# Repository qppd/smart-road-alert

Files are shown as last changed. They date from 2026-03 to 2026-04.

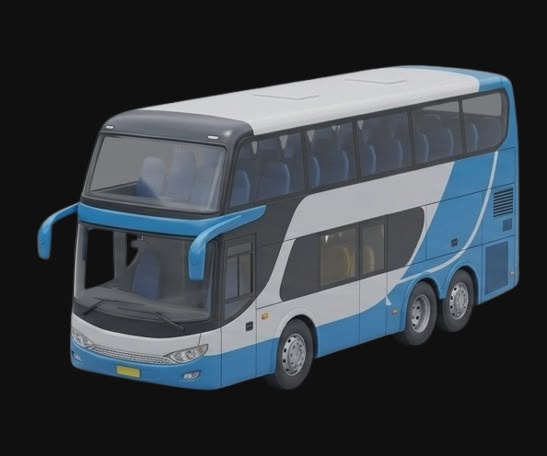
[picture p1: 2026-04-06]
src/rpi/SmartRoadAlertHost/images/bus.jpg

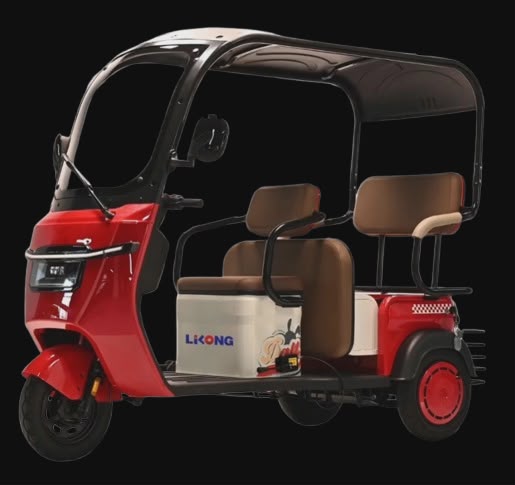
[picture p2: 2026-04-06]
src/rpi/SmartRoadAlertHost/images/ev_large.jpg

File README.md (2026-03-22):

# Smart Road Alert System

A real-time vehicle detection and alert system for improving driver safety on narrow, curved, and inclined roads through autonomous inter-post communication and intelligent traffic prioritization.

## Overview

Smart Road Alert is an intelligent roadside alert system designed for narrow, curved, and inclined road segments where restricted sightlines create blind spots and collision hazards. The system uses computer vision to detect approaching vehicles, estimate their speed and size, and communicate this information wirelessly between two roadside posts. Each post autonomously generates real-time driver alerts via LED displays and audio warnings.

This is a **two-node, symmetric, peer-to-peer architecture** where each post operates identically and bidirectionally, allowing drivers approaching from either direction to receive advance warning about oncoming traffic, enabling them to stop, slow down, or proceed safely.

## Key Features

- **Real-time Vehicle Detection**: YOLOv8-based object detection with multi-class classification (bike, car, truck, emergency vehicles, etc.)
- **Speed Estimation**: Continuous vehicle speed tracking from depth camera measurements
- **Wireless P2P Communication**: Bidirectional 433 MHz HC-12 radio links between roadside posts
- **Intelligent Prioritization**: Size-based vehicle classification with emergency vehicle fast-track handling
- **Kinematic-Based Emergency Detection**: Distinguishes active emergency responses from normal emergency vehicle traffic using speed, acceleration, and variance metrics
- **Multi-Modal Alerts**: Synchronized visual (LED display) and audio (voice/tone) warnings
- **Solar-Powered Deployment**: Off-grid capable with battery storage and MPPT charge management

## System Architecture

The system consists of two independent roadside posts (Post A and Post B) at opposite ends of a road segment. Each post operates identically with the same hardware and firmware.

```
Post A                          HC-12 433 MHz                     Post B
├─ OAK-D Lite Camera           ═════════════════────────────     ├─ OAK-D Lite Camera
├─ Raspberry Pi 5              (Bidirectional)                    ├─ Raspberry Pi 5
├─ ESP32 + HC-12 Radio                                            ├─ ESP32 + HC-12 Radio
├─ P10 LED Panel                                                  ├─ P10 LED Panel
└─ Audio Module                                                   └─ Audio Module
```

### Data Flow Pipeline

```
OAK-D Lite Camera
    ↓
Raspberry Pi 5 (Detection, Speed Estimation, Packaging)
    ↓
ESP32 (HC-12 Bridge)
    ↓
HC-12 Wireless Transmission (433 MHz)
    ↓ (over air)
    ↓
Remote ESP32 (HC-12 Reception)
    ↓
Remote Raspberry Pi 5 (Decision Logic & Prioritization)
    ├─→ ESP32 (Display Commands)
    │   └─→ P10 LED Panel
    └─→ Audio Module
```

This pipeline operates **bidirectionally and simultaneously**, with each post acting as both transmitter and receiver.

## Hardware Components

### Bill of Materials

| Component | Quantity | Purpose |
|---|---|---|
| Raspberry Pi 5 | 2 | Main processing (host controller) |
| ESP32 DevKitC | 2 | Display driver and HC-12 bridge |
| OAK-D Lite Camera | 2 | Vehicle detection and distance measurement |
| HC-12 Transceiver | 2 | 433 MHz wireless P2P communication |
| P10 LED Panel (32x16) | 6 (2 per post) | Visual driver alerts |
| DFPlayer Mini | 2 | Audio alert playback |
| Raspberry Pi SD Card | 2 | OS and application storage |
| Solar Panel | 2 | Energy Generation |
| LiFePO4 Battery (12V 50Ah) | 2 | Energy storage |
| SN74HC245N Octal Buffer | 5 | DC level shifting |

### Key Hardware Details

**Raspberry Pi 5**: Central processing unit for each post. Runs vehicle detection inference, speed estimation, wireless communication management, and decision logic.

**ESP32**: Dedicated microcontroller acting as a bridge between the Raspberry Pi (USB) and HC-12 radio. Also drives the P10 LED display independently to prevent display latency from blocking main processing.

**OAK-D Lite Camera**: Stereo depth camera with onboard Myriad X VPU. Provides high-resolution frames for detection and real-time depth (distance) measurements for speed calculation.

**HC-12 Transceiver**: Long-range, low-power 433 MHz serial radio module. Operates in transparent mode with 9600 baud UART connection to ESP32. Default channel: 433.4 MHz, Power: 20 dBm (100 mW maximum range).

**P10 LED Panel**: 32x16 high-brightness full-color LED matrix (HUB75 interface). Displays vehicle type, estimated speed, and action signal (GO, GO SLOW, STOP).

**DFPlayer Mini**: Compact MP3 player module. Plays pre-recorded voice alerts and tones from microSD card.

## Software Components

### Codebase Structure

```
src/
├── esp32/
│   └── SmartRoadAlertClient/
│       ├── SmartRoadAlertClient.ino      # Main firmware
│       ├── PINS_CONFIG.h                 # GPIO mappings
│       ├── SERIAL_CONFIG.h/cpp           # USB host communication
│       ├── HC12_CONFIG.h/cpp             # 433 MHz radio bridge
│       └── P10_LED_CONFIG.h/cpp          # Display control
│
└── rpi/
    ├── SmartRoadAlertHost/
    │   ├── main.py                       # Host controller entry point
    │   ├── serial_config.py              # ESP32 serial management
    │   └── requirements.txt              # Python dependencies
    │
    └── references/                       # Documentation and examples
```

### Raspberry Pi 5 Host (Python)

**main.py** - Entry point for the Smart Road Alert host application.

Responsibilities:
- Initialize and manage USB serial connection to ESP32 (SerialManager)
- Initialize and manage HC-12 wireless communication
- Run YOLOv8 camera inference in a background thread
- Process inbound messages from both ESP32 and remote post via HC-12
- Apply prioritization and decision logic
- Route display and audio commands
- Send periodic heartbeats and status requests

**Key Features**:
- Fully symmetric peer-to-peer architecture (both RPis run identical code)
- Thread-safe message queues for bidirectional communication
- Automatic ESP32 port discovery and reconnection
- Real-time camera inference (YOLOv8n at ~20 FPS)
- Graceful SIGINT/SIGTERM shutdown

**serial_config.py** - SerialManager module for USB communication with ESP32.

Handles:
- Automatic ESP32 device discovery (VID:PID matching)
- Handshake protocol (HELLO/ESP32_READY)
- Non-blocking line reader thread
- Connection monitoring and automatic reconnection
- Thread-safe message queue

### ESP32 Firmware (C++)

**SmartRoadAlertClient.ino** - Main firmware for ESP32.

Responsibilities:
1. Maintain USB-serial handshake link with host RPi (host heartbeat detection)
2. Drive the P10 HUB75 LED matrix display
3. Act as a transparent bridge for HC-12 radio traffic:
   - Receive `HC12_SEND` messages from RPi, transmit payload via HC-12
   - Receive HC-12 messages, wrap and forward to RPi as `HC12_RECV`
4. Forward vehicle telemetry data to RPi

**Communication Protocol**:
```
RPi → ESP32 (USB):
  {"type":"HC12_SEND","payload":"<escaped-json>"}

ESP32 → HC-12:
  <raw-json>

HC-12 → Remote ESP32 → Remote RPi (USB):
  {"type":"HC12_RECV","payload":"<escaped-json>"}
```

**Configuration Headers**:
- `PINS_CONFIG.h`: GPIO pin assignments for display, HC-12, serial
- `SERIAL_CONFIG.h`: USB communication parameters (baud, timeouts, handshake)
- `HC12_CONFIG.h`: HC-12 module settings (AT commands, baud, power)
- `P10_LED_CONFIG.h`: LED display refresh rates and rendering functions

## Communication Protocol

### HC-12 Wireless Link (433 MHz)

- **Frequency**: 433.4 MHz (default channel)
- **Baud Rate**: 9600 bps (factory default)
- **Power**: 20 dBm (100 mW, maximum range)
- **Range**: Up to 1 km in open field conditions
- **Message Format**: JSON over transparent UART

### Serial Communication Layers

```
Host RPi ←→ [USB Serial 115200 baud] ←→ ESP32 ←→ [UART 9600 baud] ←→ HC-12 Radio
```

The ESP32 acts as a bridge, transparently forwarding HC-12 messages while also managing P10 LED display updates independently.

### Message Types

**Vehicle Detection** (Local → Remote):
```json
{
  "type": "vehicle",
  "class": "truck",
  "speed": 25.5,
  "distance": 42.3,
  "timestamp": 1234567890.5
}
```

**RPI Heartbeat** (P2P):
```json
{
  "type": "RPI_PING",
  "node": "rpi-001"
}
```

**Display Command** (RPi → ESP32):
```json
{
  "cmd": "display",
  "state": "STOP",
  "vehicle": "truck",
  "speed": 25.5
}
```

## Vehicle Detection & Speed Estimation

### Detection Methods

The system supports two detection configurations:

**YOLOv8n (Recommended)**: YOLOv8 nano model running on Raspberry Pi 5 via ultralytics library. Achieves 20+ FPS on RPi 5 with headless deployment.

**DepthAI Pipeline** (Optional): YOLO inference running on OAK-D Lite's Myriad X VPU, enabling on-camera inference and spatial coordinate extraction. Reduces RPi CPU load at the cost of less flexible model updates.

### Supported Vehicle Classes

- **Small**: Bicycle, Motorcycle, EV Small
- **Medium**: Car, Tricycle, Tuktuk, Kariton, Police Car
- **Large**: Van, Jeepney, Bus, Truck, Ambulance, Fire Truck

### Speed Estimation Algorithm

Speed is estimated by tracking depth changes across consecutive frames:

```
speed (km/h) = (Δdistance / Δtime) × 3.6
```

Where:
- Δdistance = change in depth (meters) between consecutive frames
- Δtime = time elapsed between frames (seconds)
- 3.6 = conversion factor from m/s to km/h

Speed measurements are collected over a sliding observation window (0.5-1.0 second) to compute:
- **Mean Speed**: For direct alert decisions
- **Speed Variance** (std dev): For emergency vehicle kinematic detection
- **Acceleration**: For emergency response inference

## Decision Logic & Alert System

### Vehicle Prioritization (Normal Mode)

In normal (non-emergency) operation, the system prioritizes vehicles by size class:

```
Priority 1 (STOP) : Large Vehicles    (Van, Jeepney, Bus, Truck)
Priority 2 (WARN) : Medium Vehicles   (Car, Tricycle, Police Car)
Priority 3 (INFO) : Small Vehicles    (Motorcycle, Bicycle)
```

**Rationale**: Larger vehicles occupy more road width, require longer stopping distances on inclines, and create greater obstruction on curves. Therefore, larger vehicles receive right-of-way to minimize collision risk.

### Alert States

The P10 display shows one of three driver action signals:

- **GO**: Road is clear or low-obstruction vehicle detected. Drivers may proceed normally.
- **GO SLOW**: Medium-priority vehicle detected. Drivers should proceed with caution at reduced speed.
- **STOP**: Large vehicle detected or high-obstruction condition. Drivers must wait.

### Emergency Mode Detection

Emergency vehicles (ambulance, fire truck, police car) trigger **Emergency Mode** when detected with kinematic evidence of active emergency response. Three independent conditions can activate Emergency Mode:

**1. Speed Threshold**:
```
Detected Speed >= (Average Road Speed + Threshold)
```
Thresholds (road-type specific):
- Narrow or Curved: +10 km/h above average
- Inclined: +15 km/h above average
- Combined: +15 km/h above average

**2. Aggressive Acceleration**:
```
Longitudinal Acceleration >= 1.5 m/s² sustained for ≥ 2 seconds
```

**3. Speed Variance**:
```
Standard Deviation of Speed >= Variance Threshold (3-5 km/h default)
```

Emergency Mode requires **both emergency vehicle class AND at least one kinematic condition**. This dual-evidence requirement prevents false positives from static emergency vehicles or brief non-emergency speed bursts.

**Algorithm** (simplified):
```
Emergency Mode = (Emergency Vehicle Class Detected)
                 AND
                 [
                   (Speed >= Avg + Threshold)
                   OR (Acceleration >= 1.5 m/s²)
                   OR (Variance >= Threshold)
                 ]
```

### Emergency Mode Behavior

When Emergency Mode is activated:
- Emergency vehicle receives highest priority, overriding normal size-based prioritization
- Ambulances supersede all other vehicles including trucks
- Fire trucks prioritized based on speed/acceleration conditions (not variance alone)
- Police cars follow standard Emergency Mode logic
- Remote post immediately receives STOP signal
- LED display shows prominent emergency warning
- Audio module plays emergency alert tone

## Project Structure

```
smart-road-alert/
├── README.md                          # This file
├── LICENSE                            # MIT License
├── src/
│   ├── esp32/SmartRoadAlertClient/   # ESP32 firmware
│   │   ├── *.ino, *.h, *.cpp
│   │   └── PINS_CONFIG.h             # GPIO reference
│   │
│   ├── rpi/SmartRoadAlertHost/       # Raspberry Pi host application
│   │   ├── main.py                   # Entry point
│   │   ├── serial_config.py          # ESP32 manager
│   │   └── requirements.txt
│   │
│   └── sample/                        # Reference code & examples
│       ├── P10Led/                    # LED panel examples
│       └── yolo/                      # YOLO inference examples
│
└── wiring/
    └── SmartRoadAlertWiringDiagram.fzz  # Fritzing circuit diagram
```

## Dependencies

### Raspberry Pi 5 Host

**Python 3.8+** with the following packages:

```
pyserial>=3.5                          # USB serial communication
RPi.GPIO>=0.7.0                        # HC-12 SET pin control (GPIO17)
ultralytics>=8.0.0                     # YOLOv8n model and inference
opencv-python-headless>=4.8.0          # Camera capture (headless, no GUI)
```

Install via:
```bash
cd src/rpi/SmartRoadAlertHost
pip install -r requirements.txt
```

### ESP32 Firmware

Requires **Arduino IDE** or **PlatformIO** with:
- ESP32 board support package
- Arduino core for ESP32
- Standard libraries (Arduino.h, SoftwareSerial, etc.)

### Hardware Requirements

- Raspberry Pi 5 (2x for full system)
- ESP32 DevKitC (2x)
- OAK-D Lite camera (1x minimum, ideally 2x for testing)
- Linux OS (Raspberry Pi OS or similar)
- USB-A to Micro-B cable for ESP32 serial connection

## Configuration

### ESP32 Pin Configuration

Edit [src/esp32/SmartRoadAlertClient/PINS_CONFIG.h](src/esp32/SmartRoadAlertClient/PINS_CONFIG.h):

```cpp
#define PIN_HC12_RX   16   // HC-12 receives from this GPIO
#define PIN_HC12_TX   17   // HC-12 transmits to this GPIO
#define PIN_HC12_SET  22   // HC-12 mode select (LOW=AT, HIGH=transparent)
#define PIN_P10_A     12   // P10 address lines
#define PIN_P10_B     13
// ... (see full file for complete mapping)
```

### HC-12 Module Settings

Default configuration (factory settings):
- Mode: FU3 (transparent operation)
- Baud: 9600 bps
- Channel: CH001 (433.4 MHz)
- Power: Level 8 (20 dBm)

To configure via AT commands, set HC-12 SET pin LOW. [HC12_CONFIG.h](src/esp32/SmartRoadAlertClient/HC12_CONFIG.h) handles this automatically on startup.

### Raspberry Pi Host Configuration

Edit [src/rpi/SmartRoadAlertHost/main.py](src/rpi/SmartRoadAlertHost/main.py):

```python
ESP32_ENABLED: bool = True                    # Enable/disable ESP32
CAMERA_INFERENCE_ENABLED: bool = True         # Enable/disable camera
PING_INTERVAL_S: float = 5.0                  # Heartbeat interval
HC12_PING_INTERVAL_S: float = 5.0             # HC-12 heartbeat
NODE_ID: str = socket.gethostname()           # Node identifier
```

## Installation & Setup

### 1. Flash ESP32 Firmware

```bash
# Clone or download the repository
cd src/esp32/SmartRoadAlertClient

# Option A: Arduino IDE
# 1. Open SmartRoadAlertClient.ino
# 2. Select Board: ESP32 DevKitC
# 3. Select Port: /dev/ttyUSB0 or COM port
# 4. Click Upload

# Option B: PlatformIO (if using VSCode)
# 1. Install PlatformIO extension
# 2. Run: pio run -t upload
```

Verify upload in serial monitor (9600 baud):
```
[SmartRoadAlertClient] Ready
```

### 2. Install Raspberry Pi OS on RPi 5

- Download Raspberry Pi Imager
- Flash Raspberry Pi OS (64-bit) to SD card
- Enable SSH and I2C during imaging (optional but recommended)
- Boot and configure

### 3. Install Python Dependencies

```bash
cd src/rpi/SmartRoadAlertHost

# Create virtual environment (recommended)
python3 -m venv venv
source venv/bin/activate

# Install dependencies
pip install --upgrade pip
pip install -r requirements.txt

# Note: RPi.GPIO requires hardware GPIO access; test with:
python3 -c "import RPi.GPIO; print('GPIO OK')"
```

### 4. Test USB Connection to ESP32

```bash
cd src/rpi/SmartRoadAlertHost

# Quick connection test
python3 -c "from serial_config import SerialManager; m = SerialManager(); m.start(); print('Connected:', m.is_connected()); m.stop()"
```

Expected output:
```
15:32:01 [INFO] serial_config: Attempting to connect to ESP32...
15:32:02 [INFO] serial_config: Connection established; handshake successful.
Connected: True
```

### 5. Run Host Application

```bash
cd src/rpi/SmartRoadAlertHost
python3 main.py
```

Expected console output:
```
2026-03-22 15:32:15 [INFO] SmartRoadAlert: Smart Road Alert Host starting.
2026-03-22 15:32:16 [INFO] SmartRoadAlert: Camera inference thread started.
2026-03-22 15:32:16 [INFO] SmartRoadAlert: Main loop running. Press Ctrl+C to stop.
```

## Usage & Operation

### System Operation

Once both posts are running, they automatically:

1. **Detect Vehicles**: YOLOv8 runs at ~20 FPS, classifying all visible vehicles
2. **Estimate Speed**: Continuous depth tracking produces real-time speed estimates
3. **Exchange Data**: Each post wirelessly transmits its local detections to the remote post via HC-12
4. **Apply Logic**: Receive local and remote data, prioritize by size/emergency status
5. **Display Alerts**: Update LED panel and play audio warnings based on decision logic

### Example Scenario

**Scenario**: A motorcycle (low priority) approaches Post A from the left at 12 km/h; no vehicles at Post B.

**Post A Actions**:
1. Detects motorcycle via OAK-D Lite
2. Estimates speed: 12 km/h
3. Transmits via HC-12: `{"type":"vehicle","class":"motorcycle","speed":12,"distance":25}`
4. Applies logic: low-priority vehicle, safe passage
5. Sends to ESP32: `{"cmd":"display","state":"GO","vehicle":"motorcycle"}`
6. P10 LED shows: motorcycle icon, "12 km/h", "GO" signal
7. Audio module: silent (GO state)

**Post B Actions**:
1. Receives motorcycle data from remote Post A via HC-12
2. No local detections
3. Applies logic: single low-priority vehicle, safe for drivers on Post B side
4. Sends to ESP32: `{"cmd":"display","state":"GO SLOW"}`
5. P10 LED shows: motorcycle icon, "GO SLOW" signal
6. Audio module: "Vehicle approaching, proceed with caution"

### Emergency Vehicle Example

**Scenario**: An ambulance detected at Post A traveling at 40 km/h (average road speed: 20 km/h).

**Detection Phase**:
1. YOLOv8 detects class: "ambulance"
2. Speed estimate: 40 km/h
3. Acceleration: 1.8 m/s² (sustained)
4. Emergency Mode Trigger: YES (speed >= 20 + 15, acceleration >= 1.5 m/s²)

**Response**:
- Post A LED: Shows emergency warning + "STOP" signal
- Post A Audio: "EMERGENCY VEHICLE - PLEASE STOP"
- HC-12 transmits: `{"type":"vehicle","class":"ambulance","emergency":true,"speed":40}`
- Post B LED: Shows emergency warning + "STOP" signal (highest priority override)
- Post B Audio: "Emergency vehicle approaching - stop immediately"

### Monitoring & Debugging

Check system status in real-time:

```bash
# Monitor console output (already visible during main.py execution)
# Press Ctrl+C to gracefully stop

# Check HC-12 communication:
# Monitor serial output on both RPis to verify wireless packet exchange

# Test camera:
python3 -c "import cv2; cap = cv2.VideoCapture(0); print('Camera:', cap.isOpened())"

# Check system logs:
journalctl -u smartroadaler -f  # If installed as systemd service
```

## Troubleshooting

| Issue | Cause | Solution |
|---|---|---|
| ESP32 not detected | USB not connected or wrong SO baud rate | Check /dev/ttyUSB* ports, reinstall drivers |
| Handshake timeout | Serial connection unstable | Try higher baud rate, shorter USB cable |
| No HC-12 communication | Radio not powered or wrong channel | Verify power supply, check AT command config |
| YOLOv8 not starting | ultralytics package missing | `pip install ultralytics` |
| Camera not found | /dev/video0 unavailable | Check USB camera connection, list with `ls /dev/video*` |
| P10 display blank | GPIO pin mismatch or power issue | Verify PINS_CONFIG.h, check 5V supply to LED panel |

## Performance Metrics (Reference)

- **Detection FPS**: 20+ FPS (YOLOv8n on RPi 5)
- **Speed Estimation Latency**: <100 ms per frame
- **HC-12 Wireless Range**: Up to 1 km (open field)
- **HC-12 Message Latency**: 10-50 ms per message
- **LED Display Refresh**: 60 Hz (16.7 ms per frame)
- **Decision Logic Latency**: <50 ms (prioritization + routing)

**Total System Latency**: ~200-300 ms from detection at Post A to alert display at Post B (under ideal conditions).

## Future Improvements

- **DepthAI Pipeline**: Offload detection to OAK-D Lite VPU for lower RPi CPU load
- **Machine Learning**: Train custom YOLO model on local road vehicle dataset for improved accuracy
- **Sensor Fusion**: Combine camera with radar or LiDAR for robust detection in adverse weather
- **Advanced Analytics**: Track vehicle history, detect unusual patterns, generate statistical reports
- **Web Dashboard**: Remote monitoring of both posts via HTTP/MQTT
- **Mobile App**: Driver notifications via Bluetooth or cellular link
- **Enhanced Audio**: Context-aware alerts ("Truck from left approaching, slow down")

## License

This project is licensed under the MIT License. See [LICENSE](LICENSE) file for details.

## Authors

Developed by Sajed Lopez Mendoza (2026)

---

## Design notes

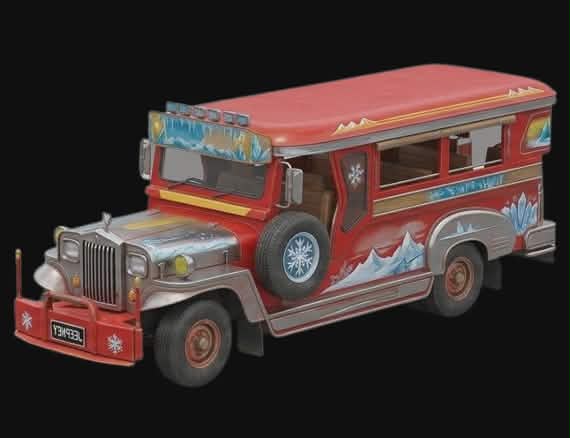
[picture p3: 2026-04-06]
src/rpi/SmartRoadAlertHost/images/jeepney.jpg

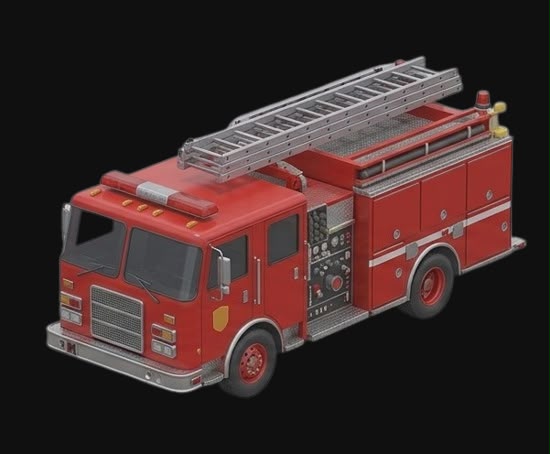
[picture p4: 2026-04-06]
src/rpi/SmartRoadAlertHost/images/fire_truck.jpg

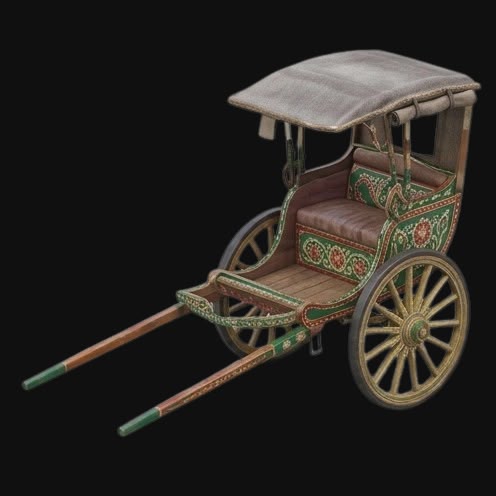
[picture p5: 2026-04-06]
src/rpi/SmartRoadAlertHost/images/kalesa.jpg

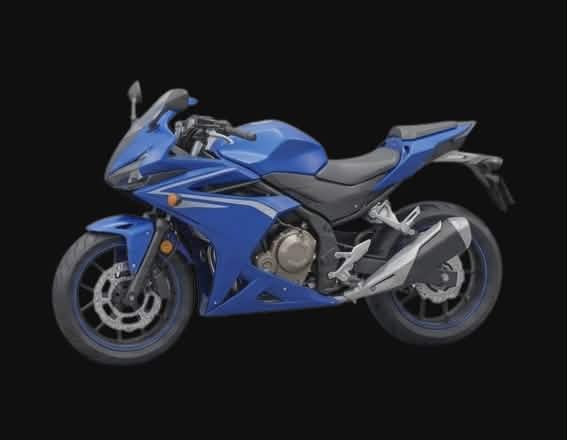
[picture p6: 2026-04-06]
src/rpi/SmartRoadAlertHost/images/motorcycle.jpg

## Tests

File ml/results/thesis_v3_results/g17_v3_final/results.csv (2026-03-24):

epoch | time | train/box_loss | train/cls_loss | train/dfl_loss | metrics/precision(B) | metrics/recall(B) | metrics/mAP50(B) | metrics/mAP50-95(B) | val/box_loss | val/cls_loss | val/dfl_loss | lr/pg0 | lr/pg1 | lr/pg2
1 | 281.22 | 1.155 | 2.51347 | 1.59304 | 0.52115 | 0.16212 | 0.23433 | 0.11267 | 1.77787 | 4.39648 | 2.48906 | 0.000199715 | 0.000199715 | 0.0802282
2 | 549.412 | 1.16046 | 1.92819 | 1.58951 | 0.41353 | 0.24831 | 0.29605 | 0.15431 | 1.61217 | 2.9318 | 2.20835 | 0.000399617 | 0.000399617 | 0.0604281
3 | 819.073 | 1.14322 | 1.78064 | 1.57525 | 0.61377 | 0.51159 | 0.58333 | 0.37472 | 1.29381 | 1.66374 | 1.87629 | 0.000599129 | 0.000599129 | 0.0406276
4 | 1087.75 | 1.10328 | 1.63924 | 1.53867 | 0.67778 | 0.56526 | 0.64407 | 0.40053 | 1.39673 | 1.54989 | 1.97653 | 0.000797958 | 0.000797958 | 0.0208264
5 | 1358.74 | 1.08631 | 1.57267 | 1.52569 | 0.68711 | 0.64275 | 0.70148 | 0.4493 | 1.29241 | 1.29992 | 1.84193 | 0.000995813 | 0.000995813 | 0.0010243
6 | 1631.35 | 1.06727 | 1.50442 | 1.5104 | 0.72316 | 0.67752 | 0.73712 | 0.49512 | 1.1786 | 1.21332 | 1.75368 | 0.000993906 | 0.000993906 | 0.000993906
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

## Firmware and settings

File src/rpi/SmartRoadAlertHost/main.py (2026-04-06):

"""
main.py

Smart Road Alert — Raspberry Pi Host Controller

Entry point for the Smart Road Alert host application.

Responsibilities:
    - Initialise and start the SerialManager (ESP32 ↔ RPi USB link).
    - Initialise and start the HC12Manager (RPi 1 ↔ RPi 2 peer-to-peer wireless).
    - Main thread: process inbound ESP32 and HC-12 messages, forward telemetry,
      and send periodic commands.
    - Graceful shutdown on SIGINT / SIGTERM.

Architecture (Fully Symmetric Peer-to-Peer):
    Both RPis run identical code with identical hardware. Each RPi:
    ✓ Has a local ESP32 (USB).
    ✓ Has an HC-12 radio module (UART /dev/ttyS0).
    ✓ Communicates bidirectionally with the peer RPi via HC-12.
    ✓ Processes and forwards telemetry from both local and remote sources.

    RPi 1              HC-12 433 MHz              RPi 2
    ├─ ESP32 [USB]  ────────────────────────  ESP32 [USB]
    └─ HC-12 Radio  ════════════════════════  HC-12 Radio

All serial communication is accessed exclusively through each manager's API.
This file does NOT import the 'serial' package directly.
"""

from __future__ import annotations

import json
import logging
import math
import os
import queue
import signal
import subprocess
import sys
import tempfile
import threading
import time
from collections import deque
from typing import Optional

import socket

from serial_config import SerialManager

# ─── Logging Configuration ────────────────────────────────────────────────────


# ─── Logging to Console and File ─────────────────────────────────────────────
LOG_FILE_PATH = os.path.join(os.path.dirname(__file__), "smart_road_alert.log.txt")
log_formatter = logging.Formatter("%(asctime)s [%(levelname)s] %(name)s: %(message)s")

file_handler = logging.FileHandler(LOG_FILE_PATH, mode="a", encoding="utf-8")
file_handler.setFormatter(log_formatter)
file_handler.setLevel(logging.INFO)

console_handler = logging.StreamHandler(sys.stdout)
console_handler.setFormatter(log_formatter)
console_handler.setLevel(logging.INFO)

logger = logging.getLogger("SmartRoadAlert")
logger.setLevel(logging.INFO)
logger.handlers.clear()
logger.addHandler(console_handler)
logger.addHandler(file_handler)

# ─── Optional Camera Inference Imports ────────────────────────────────────────

try:
    import cv2
    import depthai as dai
    from ultralytics import YOLO as _YOLO
    _CAMERA_INFERENCE_AVAILABLE = True
except ImportError:
    cv2 = None        # type: ignore[assignment]
    dai = None        # type: ignore[assignment]
    _YOLO = None      # type: ignore[assignment]
    _CAMERA_INFERENCE_AVAILABLE = False

try:
    from gtts import gTTS as _gTTS
    _GTTS_AVAILABLE = True
except ImportError:
    _gTTS = None
    _GTTS_AVAILABLE = False

try:
    from PIL import Image as _PILImage
    _PIL_AVAILABLE = True
except ImportError:
    _PILImage = None  # type: ignore[assignment]
    _PIL_AVAILABLE = False

try:
    import customtkinter as ctk
    _CTK_AVAILABLE = True
except ImportError:
    ctk = None  # type: ignore[assignment]
    _CTK_AVAILABLE = False

# ─── Application Timing Constants ─────────────────────────────────────────────

# Whether to attempt connection to a local ESP32 device via USB.
# Both RPis have their own ESP32 attached, so this should be True on both.
ESP32_ENABLED: bool = True

# Whether to start YOLOv8n camera inference (requires ultralytics + opencv).
CAMERA_INFERENCE_ENABLED: bool = True

# How often to send a PING command to the ESP32 (seconds).
PING_INTERVAL_S: float   = 5.0

# How often to request a status report from the ESP32 (seconds).
STATUS_INTERVAL_S: float = 10.0

# Main-loop message-poll interval (seconds).  Short to minimise latency.
POLL_INTERVAL_S: float   = 0.05

# How often to send an HC-12 heartbeat ping to the remote RPi (seconds).
HC12_PING_INTERVAL_S: float = 5.0

# Node identifier used in peer-to-peer HC-12 messages (hostname-based).
NODE_ID: str = socket.gethostname()

# ─── Vehicle Tracking & Speed Estimation Constants ────────────────────────────

# All vehicle classes the YOLO model can detect.
VEHICLE_CLASSES: list[str] = [
    "ambulance", "bicycle", "bus", "car", "ev_large", "ev_small",
    "fire_truck", "jeepney", "kalesa", "kariton", "motorcycle",
    "pedicab", "police_car", "tricycle", "truck", "tuktuk", "van",
]

# Emergency vehicle classes — trigger priority alerts.
_EMERGENCY_CLASSES: frozenset = frozenset({"ambulance", "fire_truck", "police_car"})

# Conversion factor: pixels (linear dimension) → metres.
# Tune based on camera mounting height and road width visible in frame.
METERS_PER_PIXEL: float = 0.03

# Minimum inter-frame time gap before speed is computed (seconds).
_MIN_TIME_DELTA: float = 0.2

# Minimum linear size change (pixels) to consider vehicle moving (noise floor).
# Raised from 2.0 to filter YOLO bbox jitter on stationary objects.
_MIN_SIZE_CHANGE: float = 6.0

# Minimum bounding-box area (pixels²) — filters tiny / noisy detections.
_MIN_BBOX_AREA: int = 500

# Maximum centroid distance (pixels) to associate a detection with an existing track.
_MAX_CENTROID_DISTANCE: float = 120.0

# Minimum number of frames a track must be alive before telemetry is sent.
_MIN_STABLE_FRAMES: int = 3

# Seconds without a detection before a track is discarded.
_TRACK_TIMEOUT_S: float = 2.0

# Minimum interval between HC-12 telemetry sends per track (seconds).
_SEND_INTERVAL_S: float = 1.0

# Maximum history entries per track (deque maxlen).
_TRACK_HISTORY_LEN: int = 10

# ─── Speed Smoothing ──────────────────────────────────────────────────────────

# Exponential moving average factor.  Lower = smoother; higher = responsive.
_SPEED_EMA_ALPHA: float = 0.3

# Max speed measurements kept per track for variance / acceleration.
_SPEED_HISTORY_LEN: int = 20

# ─── Distance Estimation (Bbox Fallback) ──────────────────────────────────────

# Reference bbox area (px²) at 1 m.  distance ≈ sqrt(REF / area) metres.
# Tune per camera mount height and lens field-of-view.
_REF_BBOX_AREA_AT_1M: float = 50000.0

# ─── Emergency Detection Thresholds ──────────────────────────────────────────

# Minimum speed (km/h) for an emergency vehicle to be considered "active".
_EMERGENCY_SPEED_THRESHOLD: float = 40.0

# Minimum longitudinal acceleration (m/s²) for emergency inference.
_EMERGENCY_ACCEL_THRESHOLD: float = 1.5

# Speed standard-deviation (km/h) threshold for erratic-driving detection.
_EMERGENCY_VARIANCE_THRESHOLD: float = 4.0

# ─── Vehicle Size Classification ─────────────────────────────────────────────

_LARGE_VEHICLES: frozenset = frozenset({
    "bus", "truck", "van", "jeepney",
    "fire_truck", "ambulance",
})
_MEDIUM_VEHICLES: frozenset = frozenset({
    "car", "tricycle", "tuktuk", "police_car", "kalesa", "ev_large", "kariton"
})
# All others (motorcycle, bicycle, pedicab) are implicitly SMALL.

# ─── Alert Signal Thresholds ─────────────────────────────────────────────────

# Speed (km/h) above which a large incoming vehicle triggers STOP.
_STOP_SPEED_THRESHOLD: float = 60.0

# Speed (km/h) above which a medium incoming vehicle triggers GO SLOW.
_SLOW_SPEED_THRESHOLD: float = 20.0


# ─────────────────────────────────────────────────────────────────────────────
# TTSManager — Non-blocking text-to-speech
# ─────────────────────────────────────────────────────────────────────────────

class TTSManager:
    """Non-blocking text-to-speech manager using gTTS.

    - Background worker thread processes a message queue.
    - Deduplicates: same message won't repeat within cooldown.
    - Rate-limits: minimum interval between any playback.
    """

    _MIN_INTERVAL_S: float = 3.0
    _SAME_MSG_COOLDOWN_S: float = 10.0

    def __init__(self) -> None:
        self._queue: queue.Queue[str] = queue.Queue(maxsize=5)
        self._last_played: dict[str, float] = {}
        self._last_any: float = 0.0
        self._running: bool = True
        self._thread = threading.Thread(
            target=self._worker, name="tts-worker", daemon=True)
        self._thread.start()
        logger.info("TTSManager: worker thread started.")

    def speak(self, text: str, force: bool = False) -> None:
        """Queue a TTS message (non-blocking, drops if queue full or throttled)."""
        now = time.monotonic()
        if not force:
            if now - self._last_any < self._MIN_INTERVAL_S:
                return
            last = self._last_played.get(text)
            if last is not None and now - last < self._SAME_MSG_COOLDOWN_S:
                return
        try:
            self._queue.put_nowait(text)
        except queue.Full:
            pass

    def stop(self) -> None:
        self._running = False
        self._thread.join(timeout=3)
        logger.info("TTSManager: stopped.")

    def _worker(self) -> None:
        while self._running:
            try:
                text = self._queue.get(timeout=1.0)
            except queue.Empty:
                continue
            now = time.monotonic()
            self._last_played[text] = now
            self._last_any = now
            tmp_path: Optional[str] = None
            try:
                tts = _gTTS(text=text, lang='en')
                fd, tmp_path = tempfile.mkstemp(suffix='.mp3')
                os.close(fd)
                tts.save(tmp_path)
                subprocess.run(
                    ['mpg123', '-q', tmp_path],
                    timeout=15, capture_output=True, check=False,
                )
                logger.debug("TTS played: %s", text)
            except FileNotFoundError:
                logger.warning(
                    "TTS: 'mpg123' not found — install it for audio playback.")
            except Exception as exc:
                logger.warning("TTS playback error: %s", exc)
            finally:
                if tmp_path is not None:
                    try:
                        os.unlink(tmp_path)
                    except OSError:
                        pass


# ─────────────────────────────────────────────────────────────────────────────
# DashboardGUI — Fullscreen roadside traffic display
# ─────────────────────────────────────────────────────────────────────────────

class DashboardGUI:
    """Fullscreen, animated traffic display built with CustomTkinter.

    Design goals:
    - Looks like a real-world intelligent roadside LCD sign.
    - Massive colour-coded status dominates the screen (GO / SLOW / STOP).
    - Vehicle info shown below in large, high-contrast text.
    - Responsive: all sizes derived from screen dimensions, not fixed px.
    - Smooth pulse/fade animations driven by after() — never blocking.
    """

    # ── Colour palette ──
    _GREEN  = "#00E050"
    _YELLOW = "#FFB800"
    _RED    = "#FF2222"
    _BG     = "#08090C"
    _FG     = "#E6EDF3"
    _DIM    = "#555E6A"
    _PANEL  = "#11151C"
    _BORDER = "#1C2333"

    # ── Animation parameters ──
    _PULSE_INTERVAL_MS = 60
    _PULSE_STEPS       = 18       # half-cycle frames (bright→dim)
    _FADE_STEPS        = 10

    def __init__(self) -> None:
        ctk.set_appearance_mode("dark")
        ctk.set_default_color_theme("dark-blue")

        self.root = ctk.CTk()
        self.root.title("Smart Road Alert")
        self.root.configure(fg_color=self._BG)

        # ── Fullscreen, borderless, always-on-top ──
        self.root.attributes("-fullscreen", True)
        try:
            self.root.attributes("-topmost", True)
        except Exception:
            pass
        self.root.bind("<Escape>", lambda _e: self.root.attributes(
            "-fullscreen", False))
        self.root.bind("<F11>", lambda _e: self.root.attributes(
            "-fullscreen",
            not self.root.attributes("-fullscreen")))

        # ── Derive sizes from screen resolution ──
        sw = self.root.winfo_screenwidth()
        sh = self.root.winfo_screenheight()
        self._s = min(sw, sh)                  # reference dimension
        self._status_font_size  = max(int(self._s * 0.18), 72)
        self._vehicle_font_size = max(int(self._s * 0.07),  36)
        self._info_font_size    = max(int(self._s * 0.045), 24)
        self._header_font_size  = max(int(self._s * 0.025), 14)
        self._emerg_font_size   = max(int(self._s * 0.055), 30)
        self._pad = max(int(self._s * 0.02), 10)

        # ── Image cache and source directory ──
        self._image_cache: dict = {}
        self._IMAGES_DIR = os.path.join(
            os.path.dirname(os.path.abspath(__file__)), "images")
        # Target bounding-box for vehicle thumbnails
        self._image_size = (
            max(int(sw * 0.15), 120),
            max(int(sh * 0.20), 100),
        )

        # ── Root grid:
        #     row 0 (weight 2) → top_frame    : image | label | speed
        #     row 1 (weight 0) → separator
        #     row 2 (weight 5) → middle_frame : STATUS (dominant)
        #     row 3 (weight 0) → separator
        #     row 4 (weight 1) → bottom_frame : EMERGENCY (hidden by default)
        self.root.grid_rowconfigure(0, weight=2)
        self.root.grid_rowconfigure(1, weight=0)
        self.root.grid_rowconfigure(2, weight=5)
        self.root.grid_rowconfigure(3, weight=0)
        self.root.grid_rowconfigure(4, weight=1)
        self.root.grid_columnconfigure(0, weight=1)

        # ══════════════════════════════════════════════════════════════════
        # TOP FRAME — Row 1: vehicle image | label | speed+direction
        # ══════════════════════════════════════════════════════════════════
        top_frame = ctk.CTkFrame(self.root, fg_color=self._PANEL, corner_radius=0)
        top_frame.grid(row=0, column=0, sticky="nsew")
        top_frame.grid_columnconfigure(0, weight=2)   # image cell
        top_frame.grid_columnconfigure(1, weight=3)   # label cell
        top_frame.grid_columnconfigure(2, weight=2)   # speed cell
        top_frame.grid_rowconfigure(0, weight=1)

        # Col 0 — vehicle image (or placeholder text when unavailable)
        self._vehicle_image_label = ctk.CTkLabel(
            top_frame, text="—",
            font=ctk.CTkFont(size=self._info_font_size),
            text_color=self._DIM)
        self._vehicle_image_label.grid(
            row=0, column=0, sticky="nsew",
            padx=self._pad, pady=self._pad)

        # Col 1 — vehicle type label (large bold)
        self._vehicle_label = ctk.CTkLabel(
            top_frame, text="—",
            font=ctk.CTkFont(size=self._vehicle_font_size, weight="bold"),
            text_color=self._FG)
        self._vehicle_label.grid(
            row=0, column=1, sticky="nsew",
            padx=self._pad, pady=self._pad)

        # Col 2 — speed (top) + direction (bottom) stacked
        speed_col = ctk.CTkFrame(top_frame, fg_color=self._PANEL, corner_radius=0)
        speed_col.grid(row=0, column=2, sticky="nsew",
                       padx=self._pad, pady=self._pad)
        speed_col.grid_rowconfigure(0, weight=2)
        speed_col.grid_rowconfigure(1, weight=1)
        speed_col.grid_columnconfigure(0, weight=1)

        self._speed_label = ctk.CTkLabel(
            speed_col, text="0  km/h",
            font=ctk.CTkFont(size=self._info_font_size, weight="bold"),
            text_color=self._DIM)
        self._speed_label.grid(row=0, column=0, sticky="nsew")

        self._direction_label = ctk.CTkLabel(
            speed_col, text="—",
            font=ctk.CTkFont(size=self._header_font_size, weight="bold"),
            text_color=self._DIM)
        self._direction_label.grid(row=1, column=0, sticky="nsew")

        # ── Thin horizontal divider ──
        ctk.CTkFrame(
            self.root, fg_color=self._BORDER, height=2, corner_radius=0
        ).grid(row=1, column=0, sticky="ew")

        # ══════════════════════════════════════════════════════════════════
        # MIDDLE FRAME — Row 2: GO / SLOW / STOP  (dominant)
        # ══════════════════════════════════════════════════════════════════
        self._status_frame = ctk.CTkFrame(
            self.root, fg_color=self._BG, corner_radius=0)
        self._status_frame.grid(row=2, column=0, sticky="nsew")
        self._status_frame.grid_rowconfigure(0, weight=1)
        self._status_frame.grid_columnconfigure(0, weight=1)

        self._status_label = ctk.CTkLabel(
            self._status_frame, text="GO",
            font=ctk.CTkFont(size=self._status_font_size, weight="bold"),
            text_color=self._GREEN)
        self._status_label.grid(row=0, column=0, sticky="nsew")

        # ── Thin horizontal divider ──
        ctk.CTkFrame(
            self.root, fg_color=self._BORDER, height=2, corner_radius=0
        ).grid(row=3, column=0, sticky="ew")

        # ══════════════════════════════════════════════════════════════════
        # BOTTOM FRAME — Row 3: EMERGENCY indicator (hidden by default)
        # ══════════════════════════════════════════════════════════════════
        self._emergency_frame = ctk.CTkFrame(
            self.root, fg_color="#1A0000", corner_radius=0)
        self._emergency_frame.grid(row=4, column=0, sticky="nsew")
        self._emergency_frame.grid_rowconfigure(0, weight=1)
        self._emergency_frame.grid_columnconfigure(0, weight=1)

        self._emergency_label = ctk.CTkLabel(
            self._emergency_frame,
            text="\U0001F6A8  EMERGENCY  \U0001F6A8",
            font=ctk.CTkFont(size=self._emerg_font_size, weight="bold"),
            text_color=self._RED)
        self._emergency_label.grid(row=0, column=0, sticky="nsew")
        # Hidden until an emergency is signalled
        self._emergency_frame.grid_remove()

        # ── Internal animation / state tracking ──
        self._cur_status: str = "GO"
        self._cur_color: str = self._GREEN
        self._pulse_active: bool = False
        self._pulse_step: int = 0
        self._pulse_dir: int = 1      # 1 = dimming, -1 = brightening
        self._pulse_after_id: Optional[str] = None
        self._fade_after_id: Optional[str] = None
        self._blink_active: bool = False
        self._blink_visible: bool = True
        self._blink_after_id: Optional[str] = None
        self._emergency_visible: bool = False

        # Cached widget values to skip redundant redraws
        self._cache_vehicle: str = ""
        self._cache_speed: str = ""
        self._cache_direction: str = ""
        self._cache_emergency: Optional[bool] = None

        logger.info("DashboardGUI: fullscreen display initialised (%dx%d).", sw, sh)

    # ──────────────────────────────────────────────────────────────────────
    # Public update API (called from _gui_poll on the main thread)
    # ──────────────────────────────────────────────────────────────────────

    def update_status(self, signal_text: str, emergency: bool = False) -> None:
        """Update the central status indicator with animation."""
        if emergency or signal_text == "STOP":
            new_status, new_color = "STOP", self._RED
        elif signal_text in ("GO SLOW", "SLOW"):
            new_status, new_color = "SLOW", self._YELLOW
        else:
            new_status, new_color = "GO", self._GREEN

        if new_status == self._cur_status:
            return  # no change — skip redraw

        old_status = self._cur_status
        self._cur_status = new_status
        self._cur_color = new_color

        # Stop any running pulse before starting a new transition
        self._stop_pulse()

        # Kick off cross-fade from current label to new label
        self._animate_status_change(new_status, new_color)

        # Start continuous pulse for STOP / SLOW
        if new_status == "STOP":
            self._start_pulse(new_color, strong=True)
        elif new_status == "SLOW":
            self._start_pulse(new_color, strong=False)

    def update_vehicle_info(self, label: str, speed: float,
                            direction: str) -> None:
        """Update the vehicle info panel (only redraws on change)."""
        v_text = label.upper().replace("_", " ") if label and label != "none" else "—"
        s_text = f"{speed:.0f}  km/h" if speed > 0 else "0  km/h"
        d_text = direction.upper() if direction and direction != "NONE" else "—"

        if v_text != self._cache_vehicle:
            self._cache_vehicle = v_text
            self._vehicle_label.configure(text=v_text)
            # Load and display vehicle thumbnail (cached, no I/O on repeat calls)
            clean_label = label.lower() if label and label not in ("none", "clear") else ""
            img = self._load_vehicle_image(clean_label) if clean_label else None
            if img is not None:
                self._vehicle_image_label.configure(image=img, text="")
            else:
                self._vehicle_image_label.configure(
                    image=None, text="\U0001F697" if v_text != "—" else "—")
        if s_text != self._cache_speed:
            self._cache_speed = s_text
            self._speed_label.configure(
                text=s_text,
                text_color=self._FG if speed > 0 else self._DIM)
        if d_text != self._cache_direction:
            self._cache_direction = d_text
            self._direction_label.configure(
                text=d_text,
                text_color=self._FG if d_text != "—" else self._DIM)

    # Backward-compatible aliases used by _gui_poll
    def update_local(self, label: str, speed: float, direction: str) -> None:
        pass  # display is unified — handled via update_vehicle_info

    def update_remote(self, label: str, speed: float, direction: str) -> None:
        pass  # display is unified — handled via update_vehicle_info

    def update_display(self, status: str, label: str, speed: float,
                       direction: str, emergency: bool = False) -> None:
        """Central GUI update — single entry point from SmartRoadAlertHost.
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

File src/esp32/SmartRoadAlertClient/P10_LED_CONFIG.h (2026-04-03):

#ifndef P10_LED_CONFIG_H
#define P10_LED_CONFIG_H

#include <Arduino.h>
#include <Adafruit_GFX.h>
#include <ESP32-HUB75-MatrixPanel-I2S-DMA.h>
#include "PINS_CONFIG.h"

// =======================================================================
// P10 Full-Color Panel  |  32x16 px, 1/4-scan, HUB75, SMD3535
//
// PHYSICAL CHAIN (left -> right, viewed from front):
//
//   ESP32 -> [PANEL A IN]--[PANEL A OUT]-->[PANEL B IN]--[PANEL B OUT]-->[PANEL C IN]
//
// Stock orientation: no per-panel 90-degree rotation remap.
// Each panel stays 32x16 logical, so three chained panels are 96x16.
//
// "64x8 DMA trick": each panel is still declared as 64x8 to match
// this panel's 1/4-scan electrical layout. CustomMatrix only applies
// 1/4-scan remap + chain offset in this mode.
// =======================================================================
#define PANEL_RES_X     64   // 1/4-scan trick: 32 physical cols -> 64 DMA cols
#define PANEL_RES_Y     8    // 1/4-scan trick: 16 physical rows -> 8 DMA rows
#define PANEL_CHAIN     3    // Number of P10 panels chained

#define P10_LOGICAL_W   96   // Logical width  (PANEL_CHAIN * 32, stock orientation)
#define P10_LOGICAL_H   16   // Logical height (16 rows per panel)

// HUB75 Pin Definitions — numeric values are centralised in PINS_CONFIG.h.
// These aliases preserve backward compatibility with P10_LED_CONFIG.cpp.
#define P_R1  PIN_P10_R1
#define P_G1  PIN_P10_G1
#define P_B1  PIN_P10_B1
#define P_R2  PIN_P10_R2
#define P_G2  PIN_P10_G2
#define P_B2  PIN_P10_B2
#define P_A   PIN_P10_A
#define P_B   PIN_P10_B
#define P_C   PIN_P10_C
#define P_LAT PIN_P10_LAT
#define P_OE  PIN_P10_OE
#define P_CLK PIN_P10_CLK

// Custom Adafruit_GFX subclass that remaps logical coordinates to the
// physical DMA buffer via 1/4-scan addressing.
class CustomMatrix : public Adafruit_GFX {
public:
    MatrixPanel_I2S_DMA *dma;

    explicit CustomMatrix(MatrixPanel_I2S_DMA *d)
        : Adafruit_GFX(P10_LOGICAL_W, P10_LOGICAL_H), dma(d) {}

    void drawPixel(int16_t x, int16_t y, uint16_t color) override;
};

extern MatrixPanel_I2S_DMA *dma_display;
extern CustomMatrix         *display;

void setupP10();
void displayTextP10(const char *text);
void displayVehicleData(float speed, float distance, bool safe);
void displayAlert(const char *label, const char *signal, float speed, bool emergency);

#endif // P10_LED_CONFIG_H

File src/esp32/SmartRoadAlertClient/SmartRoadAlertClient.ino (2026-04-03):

/**
 * SmartRoadAlertClient.ino
 *
 * Smart Road Alert — ESP32 Firmware
 *
 * Responsibilities:
 *   1. Maintain the USB-serial handshake/heartbeat link with the host RPi
 *      (SERIAL_CONFIG — unchanged).
 *   2. Drive the P10 HUB75 LED matrix display (P10_LED_CONFIG — unchanged).
 *   3. Bridge HC-12 433 MHz radio traffic between the two RPis:
 *        RPi ──USB──► ESP32 ──HC-12──► remote ESP32 ──USB──► remote RPi
 *      • HC12_SEND  : RPi sends  {"type":"HC12_SEND","payload":"<escaped-json>"}
 *                     → ESP32 extracts & transmits payload via HC-12.
 *      • HC12_RECV  : HC-12 receives raw JSON from peer
 *                     → ESP32 wraps it as {"type":"HC12_RECV","payload":"<escaped-json>"}
 *                       and forwards to local RPi via USB.
 *   4. Send periodic vehicle telemetry to the RPi.
 *
 * Both ESP32 units run this identical firmware (symmetric).
 * All GPIO pin numbers are defined exclusively in PINS_CONFIG.h.
 */

#include "PINS_CONFIG.h"
#include "SERIAL_CONFIG.h"
#include "P10_LED_CONFIG.h"
#include "HC12_CONFIG.h"

static const unsigned long SENSOR_POLL_INTERVAL_MS    = 500UL;
static const unsigned long DISPLAY_UPDATE_INTERVAL_MS = 500UL;

static unsigned long s_last_sensor_poll_ms = 0;
static unsigned long s_last_display_ms     = 0;

// When a display command arrives from the RPi, the alert is shown for this
// duration before falling back to the default local-sensor display.
static const unsigned long ALERT_DISPLAY_MS = 10000UL;
static bool          s_display_alert = false;
static unsigned long s_alert_expire_ms = 0;

// Latest vehicle state, updated every sensor poll and reflected on the display
static float s_speed    = 0.0f;
static float s_distance = 0.0f;
static bool  s_safe     = true;

// ── Private prototypes ────────────────────────────────────────────────────────
static void handle_incoming_message(const SerialMessage &msg);
static void poll_and_send_sensor_data(void);
static void forward_hc12_to_rpi(const char *hc12_line);
static bool extract_json_string(const char *json, const char *key,
                                char *dst, size_t dstlen);
static void json_str_escape(char *dst, const char *src, size_t dstlen);
static float extract_json_number(const char *json, const char *key);

// ─────────────────────────────────────────────────────────────────────────────
void setup() {
    serial_init();
    setupP10();
    hc12_init();
    displayTextP10("Ready");
}

void loop() {
    serial_update();
    hc12_update();

    // Forward any HC-12 received frame to the RPi (wrapped as HC12_RECV)
    if (hc12_has_message()) {
        forward_hc12_to_rpi(hc12_get_message());
    }

    // Process commands/messages arriving from the RPi over USB
    if (serial_has_message()) {
        SerialMessage msg = serial_get_message();
        handle_incoming_message(msg);
    }

    if (serial_is_connected()) {
        poll_and_send_sensor_data();
    }

    // Refresh the P10 display at the configured interval
    unsigned long now = millis();
    if (now - s_last_display_ms >= DISPLAY_UPDATE_INTERVAL_MS) {
        s_last_display_ms = now;
        // If an RPi-driven alert is active and not expired, skip local refresh.
        if (s_display_alert && (long)(now - s_alert_expire_ms) < 0) {
            // Alert still showing — do not overwrite.
        } else {
            s_display_alert = false;
            displayVehicleData(s_speed, s_distance, s_safe);
        }
    }
}

// ─── HC-12 → RPi Bridge ───────────────────────────────────────────────────────

/**
 * Wrap a raw HC-12 received line in a HC12_RECV envelope and forward
 * it to the RPi over USB serial.
 *
 * Output format:
 *   {"type":"HC12_RECV","payload":"<json-escaped hc12_line>"}
 */
static void forward_hc12_to_rpi(const char *hc12_line) {
    char escaped[SERIAL_TX_BUFFER_SIZE];
    json_str_escape(escaped, hc12_line, sizeof(escaped));

    char out[SERIAL_TX_BUFFER_SIZE];
    snprintf(out, sizeof(out),
             "{\"type\":\"HC12_RECV\",\"payload\":\"%s\"}",
             escaped);
    serial_send(out);
}

// ─── RPi → HC-12 Bridge / Command Dispatcher ──────────────────────────────────

static void handle_incoming_message(const SerialMessage &msg) {
    if (!msg.valid || msg.raw[0] == '\0') {
        return;
    }

    // ── PING ──────────────────────────────────────────────────────────────────
    if (strstr(msg.raw, "\"cmd\":\"ping\"") != nullptr) {
        serial_send("{\"type\":\"pong\"}");
        return;
    }

    // ── STATUS ────────────────────────────────────────────────────────────────
    if (strstr(msg.raw, "\"cmd\":\"status\"") != nullptr) {
        serial_send("{\"type\":\"status\",\"state\":\"ok\"}");
        return;
    }

    // ── HC12_SEND — relay payload over the HC-12 radio link ──────────────────
    // Expected format: {"type":"HC12_SEND","payload":"<escaped-json-string>"}
    if (strstr(msg.raw, "\"type\":\"HC12_SEND\"") != nullptr) {
        char payload[SERIAL_RX_BUFFER_SIZE];
        if (extract_json_string(msg.raw, "payload", payload, sizeof(payload))) {
            hc12_send(payload);
        }
        return;
    }

    // ── HC12_TEST — diagnostic: send an arbitrary string over HC-12 ──────────
    // Expected format: {"cmd":"hc12_test","msg":"<text>"}
    if (strstr(msg.raw, "\"cmd\":\"hc12_test\"") != nullptr) {
        char test_msg[128];
        if (extract_json_string(msg.raw, "msg", test_msg, sizeof(test_msg))) {
            hc12_send(test_msg);
            serial_send("{\"type\":\"status\",\"state\":\"hc12_test_sent\"}");
        }
        return;
    }

    // ── DISPLAY — RPi-driven P10 alert display ─────────────────────────────
    // Expected: {"cmd":"display","label":"truck","signal":"STOP",
    //            "speed":45.2,"priority":"HIGH","emergency":false}
    if (strstr(msg.raw, "\"cmd\":\"display\"") != nullptr) {
        char label[32]      = {0};
        char signal_str[16] = {0};
        extract_json_string(msg.raw, "label",  label,      sizeof(label));
        extract_json_string(msg.raw, "signal", signal_str, sizeof(signal_str));
        float cmd_speed   = extract_json_number(msg.raw, "speed");
        bool is_emergency = (strstr(msg.raw, "\"emergency\":true") != nullptr);

        displayAlert(label, signal_str, cmd_speed, is_emergency);
        s_display_alert  = true;
        s_alert_expire_ms = millis() + ALERT_DISPLAY_MS;
        return;
    }

    serial_send("{\"type\":\"error\",\"msg\":\"unknown command\"}");
}

// ─── Sensor Telemetry ─────────────────────────────────────────────────────────

static void poll_and_send_sensor_data(void) {
    // No physical speed/distance sensor is connected.
    // Vehicle telemetry is provided exclusively by the RPi YOLO camera pipeline.
    // This function intentionally does nothing until a real sensor is wired up.
    (void)s_last_sensor_poll_ms;
}

// ─── JSON Numeric Utility ─────────────────────────────────────────────────────
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

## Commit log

2026-03-16 Add initial ESP32 SmartRoadAlertClient.ino with basic setup and loop
2026-03-16 Move ESP32 SmartRoadAlertClient.ino to src/esp32/SmartRoadAlertClient
2026-03-16 Add SmartRoadAlertHost/main.py as entry point for Raspberry Pi host
2026-03-16 Stage all changes with git add -A for consistency
2026-03-16 Add wiring folder at project root
    [SmartRoadAlertWiringDiagram.fzz]
2026-03-16 Implement robust ESP32↔RPi serial communication system: modular serial modules, auto port detection, threaded reconnection, JSON protocol
2026-03-16 Fix ESP32 handshake: retry HELLO, interruptible sleep for shutdown
    [serial_config.py]
2026-03-16 Fix serial stability: exclusive open, dtr=False, silence timeout; ESP32 host-silence recovery; udev rule for ModemManager
    [SERIAL_CONFIG.cpp, serial_config.py]
2026-03-18 Fix SERIAL_CONFIG.cpp: close serial_init and resolve function definition errors
    [P10Led.ino, P10_LED_CONFIG.cpp, P10_LED_CONFIG.h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]
2026-03-21 Switch DF_MINI_CONFIG to HardwareSerial (Serial2) on GPIO16/17 for ESP32
2026-03-21 Integrate threaded YOLOv8n camera inference into SmartRoadAlertHost
    - Added optional camera inference module using OpenCV (cv2.VideoCapture) and Ultralytics YOLOv8n.
    - Camera thread auto-detects first available USB camera (/dev/video*) or falls back to /dev/video0.
    - Loads YOLOv8n model in a non-blocking daemon thread; runs inference on each frame.
    - Logs detected objects (label, confidence) for every frame; provides a hook (_on_inference_detections) for further processing.
    - Camera inference is fully optional: controlled by CAMERA_INFERENCE_ENABLED and checks for required dependencies.
    - Ensures graceful shutdown: camera thread is joined in stop(), does not block main loop.
    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
2026-03-21 Add YOLOv8 detection sample script
    - Added src/sample/yolo/yolo_detect.py as a standalone example for running YOLOv8 object detection.
    - Demonstrates loading a YOLOv8 model and running inference on camera or image input.
    - Useful for testing model setup and verifying inference pipeline outside the main application.
    - No changes to core application logic or dependencies.
2026-03-21 Integrate Intel Movidius MyriadX (DepthAI/OAK-D) as video input source for YOLO pipeline
    - Added 'oak' as a new source type for automatic DepthAI/OAK-D camera detection
    - Replaced cv2.VideoCapture for 'oak' with DepthAI pipeline using ColorCamera node (1080p, BGR)
    - Used non-blocking output queue (maxSize=4) for low-latency streaming
    - Frames are acquired with getCvFrame() and fed directly to YOLO inference
    - Preserved all existing logic and architecture; no changes to YOLO pipeline or function signatures
    - Graceful error handling for device absence and import errors
    - Added proper cleanup for OAK device on exit
    - Maintained compatibility with all previous input types (image, folder, video,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
    [yolo_detect.py]
2026-03-22 CHANGE 7: Remove direct HC-12 UART code from RPi, add HC-12 bridge via ESP32, update all message paths, add PINS_CONFIG.h, HC12_CONFIG.[ch], and remove DF Mini + old hc12_config.py
2026-03-22 feat: add SpeakGTTS.py sample for gTTS speech synthesis
2026-03-23 Fix depthai API: replace createColorCamera with createRGBCamera and add cv2 import
    [oakcamera.py]
2026-03-23 Stage all changes before push
2026-03-23 Fix: use correct depthai color camera node creation method in oakcamera.py
    [oakcamera.py]
2026-03-24 Stage and push all changes
2026-03-24 Fix camera inference: use depthai v3 API (pipeline.create + requestOutput)
    [main.py]
2026-03-24 Use ncnn model, draw bounding boxes, and show imshow in camera inference
2026-03-24 Fix: move cv2.imshow and waitKey to main thread for OAK camera display reliability
    [main.py]
2026-03-24 feat(logging): log to both console and smart_road_alert.log.txt for error tracking
    [main.py]
2026-03-24 fix: use cv2.waitKey(30) for better RealVNC frame rendering over camera display loop
    [main.py]
2026-03-24 Fix DepthAI black frame bug: copy frame buffer, add debug, and robust display
    - Fixes black window by copying frame from DepthAI output queue before sharing between threads (prevents buffer reuse/zeroing)
    - Adds debug instrumentation: logs frame shape/type, prints frame validity, saves debug.jpg for inspection
    - Ensures cv2.imshow() always receives a valid, independent frame (copy-on-read in main thread)
    - Pre-creates namedWindow in main thread to avoid compositor/display race conditions
    - Maintains thread safety with frame lock
    - No change to inference or detection logic
    Root cause: DepthAI getCvFrame() returns a view into a buffer that is recycled on next q.get(); without .copy(), main th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
    [main.py]
2026-04-02 Added reference, diagnostic and sample code for P10 Led
2026-04-03 Pushing model
    [model.ncnn.param]
2026-04-03 Full system integration: real-time tracking, speed/direction, emergency detection, priority alerts, HC-12 telemetry, and ESP32 display control. See summary for details.
2026-04-03 Clean logging, 2x display, no-vehicle telemetry reset, remove ESP32 debug spam
    [HC12_CONFIG.cpp, SERIAL_CONFIG.cpp, main.py]
2026-04-03 Add telemetry HUD overlay on OpenCV window with 5s auto-reset
    [main.py]
2026-04-03 HUD overlay now shows HC-12 received telemetry, auto-reset after 5s
    [main.py]
2026-04-03 Fix ghost speed/distance: skip telemetry for tracks not matched this frame
    [main.py]
2026-04-03 Fix ghost speed: zero EMA on no-movement, reset unmatched track state, raise jitter/confidence thresholds
    [main.py]
2026-04-03 Fix HC-12 ghost speed: instant no-vehicle reset, no-detection early return, clear HUD on zero-speed remote packets
    [main.py]
2026-04-03 Remove fake ESP32 sensor data: disable hardcoded speed/distance, ignore local ESP32 vehicle packets
2026-04-03 Fix HC-12 truncated messages: skip pre-JSON preamble bytes, slim telemetry payload
    [HC12_CONFIG.cpp, main.py]
2026-04-05 Smart Road Alert: gTTS voice alerts, CustomTkinter GUI, vehicle classification fix, code cleanup
    [main.py]
2026-04-06 GUI smoothing, vehicle label, and cross-RPI priority logic: - Add 3s GUI hold after last remote telemetry for smooth transitions - Centralize GUI update via update_display() - Add cross-RPI priority 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
    [main.py]
2026-04-06 fix: RPI1 GUI not updating on remote detection
    Remove direction-based gate in _on_remote_vehicle_data.
    Previously, when RPI2 detected a vehicle as 'incoming' (approaching
    its camera), RPI1 mapped it to local_direction='outgoing' and forced
    signal='GO', causing the GUI to never change from its default state.
    Any active vehicle detected by the remote RPI now always computes
    a SLOW/STOP signal (via priority + speed), so the receiving side
    correctly shows SLOW or STOP regardless of the camera-relative
    direction label.
    [main.py]
2026-04-06 fix: both RPIs showing GO even when vehicle detected
    Root cause: _get_alert_signal() returns 'GO' for:
    - LOW priority vehicles (motorcycle, bicycle, pedicab) at any speed
    - MEDIUM priority vehicles (car, tricycle) when speed < 20 km/h
    (common in testing with phone images where speed = 0)
    Fix: in _on_remote_vehicle_data, any non-empty remote vehicle
    detection is clamped to minimum 'SLOW' before updating _remote_display.
    The GO threshold logic remains intact for local/ESP32 display but is
    no longer applied to the receiving RPI's GUI signal.
    [main.py]
2026-04-06 GUI: Add vehicle image, 3-row layout, and emergency indicator (CustomTkinter)
    - Adds dynamic vehicle image (with cache, fallback, proportional resize)
    - Rebuilds GUI into 3-row layout: [image|label|speed], [status], [emergency]
    - Large, bold, color-coded fonts for driver visibility
    - Emergency indicator row with blinking animation
    - All updates non-blocking (after()), no backend/logic changes
    - Preserves all telemetry/state/timing logic
    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
2026-04-06 fix: pass None instead of empty string to CTkLabel image to suppress CTkImage warning
    [main.py]
2026-04-06 feat: show cv2 camera feed preview window alongside CTk GUI (debug)
2026-04-06 fix: clear vehicle image/label immediately on no-vehicle packet from RPi2
    [main.py]
